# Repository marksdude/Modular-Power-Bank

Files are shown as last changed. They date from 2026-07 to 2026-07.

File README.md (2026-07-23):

# Modular-Power-Bank
A power bank with attachable modules
# Disclamer
None of the PCBs have been fully tested so I can't guarantee that they will function correctly.
# Features
- USB PD output up to 45W (may handle 60W)
- 0.91 inch OLED for status monitoring
- Attachable modules
- Repairable design
# Modules
- LED controller - Allows you to control 5V LEDs with Home Assistant

I also plan to make a LiPo charger module that will support charging up to 3S LiPos.

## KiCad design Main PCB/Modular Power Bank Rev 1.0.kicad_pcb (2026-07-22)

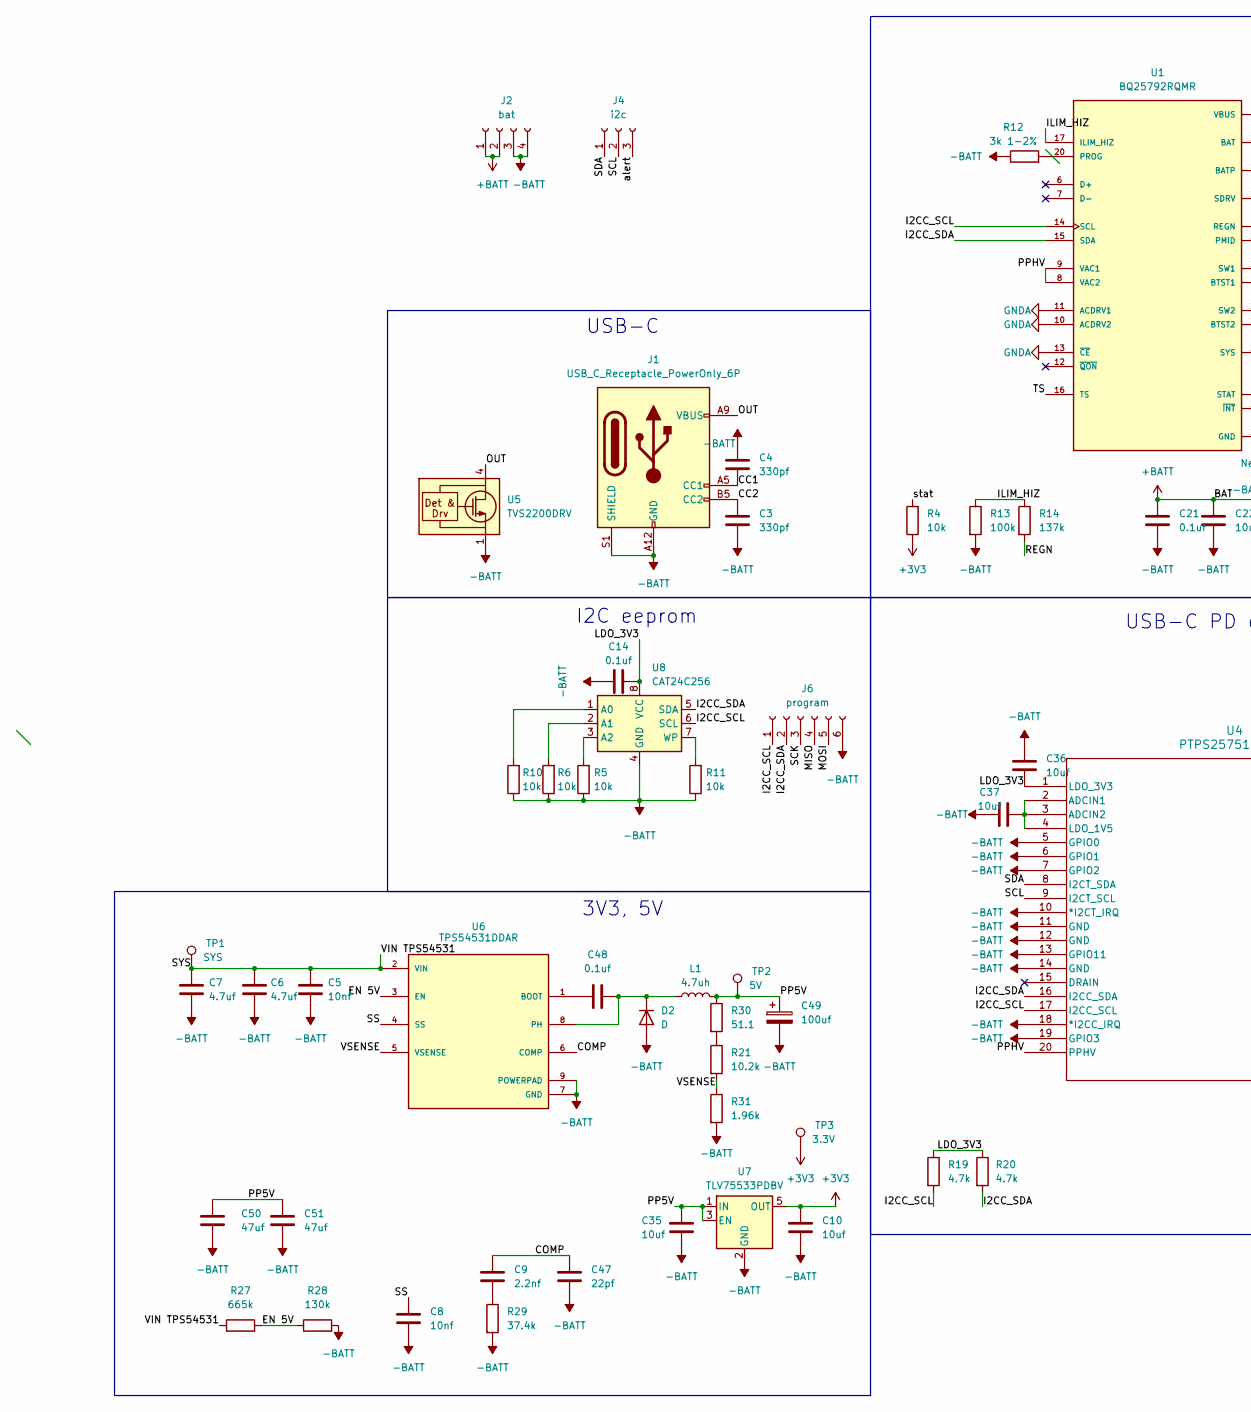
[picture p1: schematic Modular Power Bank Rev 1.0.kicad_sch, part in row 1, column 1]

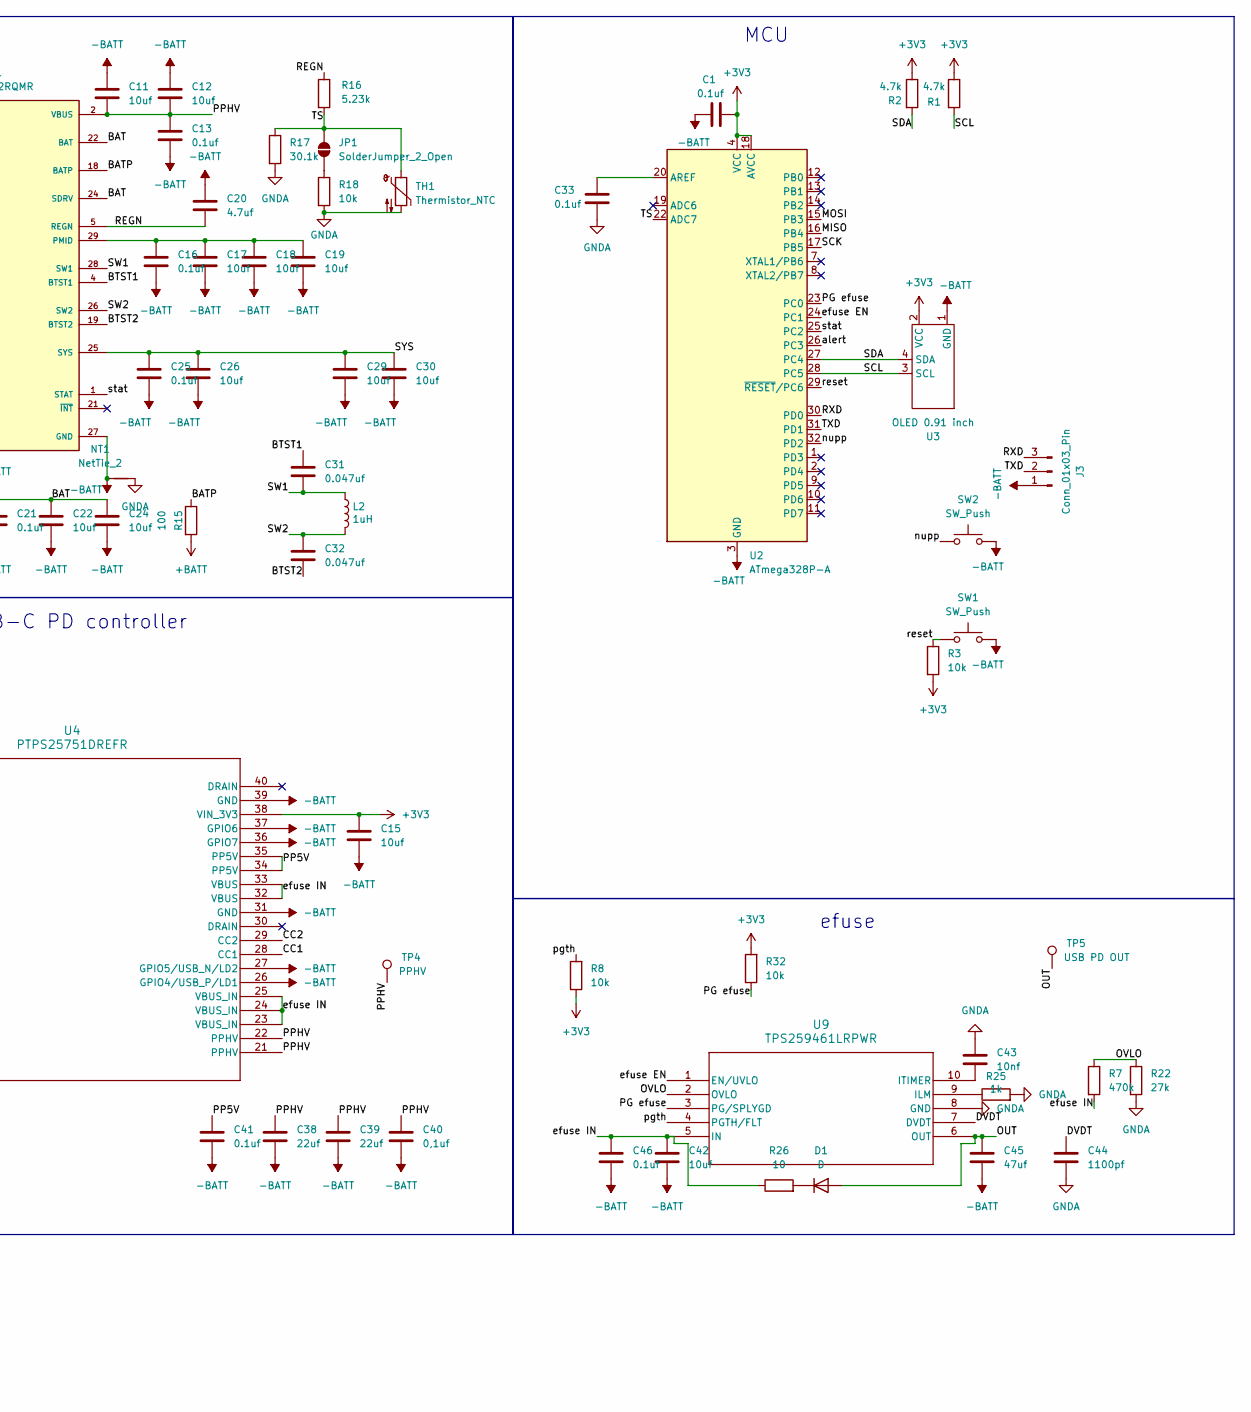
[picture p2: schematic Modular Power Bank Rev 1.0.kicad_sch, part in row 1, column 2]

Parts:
C1, C13, C14, C16, C21, C25, C33, C41, C46, C48: 0.1uf; C_0201_0603Metric_Pad0.64x0.40mm_HandSolder
C3, C4: 330pf; C_0402_1005Metric_Pad0.74x0.62mm_HandSolder
C5, C8, C43: 10nf; C_0201_0603Metric_Pad0.64x0.40mm_HandSolder
C6, C7, C20: 4.7uf; C_0402_1005Metric_Pad0.74x0.62mm_HandSolder
C9: 2.2nf; C_0402_1005Metric_Pad0.74x0.62mm_HandSolder
C10, C11, C12, C22, C24, C26, C29, C30, C35: 10uf; C_0603_1608Metric_Pad1.08x0.95mm_HandSolder
C15, C36, C37: 10uf; C_0402_1005Metric_Pad0.74x0.62mm_HandSolder
C17, C18, C19, C42: 10uf; R_0603_1608Metric_Pad0.98x0.95mm_HandSolder
C31, C32: 0.047uf; C_0402_1005Metric_Pad0.74x0.62mm_HandSolder
C38, C39: 22uf; C_0805_2012Metric_Pad1.18x1.45mm_HandSolder
C40: 0,1uf; C_0201_0603Metric_Pad0.64x0.40mm_HandSolder
C44: 1100pf; C_0402_1005Metric_Pad0.74x0.62mm_HandSolder
C45, C50, C51: 47uf; C_1210_3225Metric_Pad1.33x2.70mm_HandSolder
C47: 22pf; C_0402_1005Metric_Pad0.74x0.62mm_HandSolder
C49: 100uf; CP_Radial_D5.0mm_P2.50mm
D1: D; D_SOD-323_HandSoldering
D2: D; D_SMC
J1: USB_C_Receptacle_PowerOnly_6P; USB_C_Receptacle_GCT_USB4125-xx-x-0190_6P_TopMnt_Horizontal
J2: bat; JST_VH_S4P-VH_1x04_P3.96mm_Horizontal
J3: Conn_01x03_Pin; JST_ZH_B3B-ZR_1x03_P1.50mm_Vertical
J4: i2c; JST_ZH_B3B-ZR_1x03_P1.50mm_Vertical
J6: program; JST_ZH_B6B-ZR_1x06_P1.50mm_Vertical
JP1: SolderJumper_2_Open; SolderJumper-2_P1.3mm_Open_Pad1.0x1.5mm
L1: 4.7uh; L_Bourns_SRP1038C_10.0x10.0mm
L2: 1uH; L_Vishay_IHLP-2020
NT1: NetTie_2; NetTie-2_THT_Pad0.3mm
R1, R2: 4.7k; R_0603_1608Metric_Pad0.98x0.95mm_HandSolder
R3, R18, R32: 10k; R_0603_1608Metric_Pad0.98x0.95mm_HandSolder
R4, R5, R6, R8, R10, R11: 10k; R_0402_1005Metric_Pad0.72x0.64mm_HandSolder
R7: 470k; R_0402_1005Metric_Pad0.72x0.64mm_HandSolder
R12: 3k 1-2%; R_0402_1005Metric_Pad0.72x0.64mm_HandSolder
R13: 100k; R_0603_1608Metric_Pad0.98x0.95mm_HandSolder
R14: 137k; R_0603_1608Metric_Pad0.98x0.95mm_HandSolder
R15: 100; R_0402_1005Metric_Pad0.72x0.64mm_HandSolder
R16: 5.23k; R_0603_1608Metric_Pad0.98x0.95mm_HandSolder
R17: 30.1k; R_0603_1608Metric_Pad0.98x0.95mm_HandSolder
R19, R20: 4.7k; R_0402_1005Metric_Pad0.72x0.64mm_HandSolder
R21: 10.2k; R_0603_1608Metric_Pad0.98x0.95mm_HandSolder
R22: 27k; R_0402_1005Metric_Pad0.72x0.64mm_HandSolder
R25: 1k; R_0402_1005Metric_Pad0.72x0.64mm_HandSolder
R26: 10; R_0402_1005Metric_Pad0.72x0.64mm_HandSolder
R27: 665k; R_0603_1608Metric_Pad0.98x0.95mm_HandSolder
R28: 130k; R_0603_1608Metric_Pad0.98x0.95mm_HandSolder
R29: 37.4k; R_0402_1005Metric_Pad0.72x0.64mm_HandSolder
R30: 51.1; R_0603_1608Metric_Pad0.98x0.95mm_HandSolder
R31: 1.96k; R_0603_1608Metric_Pad0.98x0.95mm_HandSolder
SW1, SW2: SW_Push; SW_SPST_B3U-1000P
TH1: Thermistor_NTC; ntc
TP1: SYS; TestPoint_Pad_D1.0mm
TP2: 5V; TestPoint_Pad_D1.0mm
TP3: 3.3V; TestPoint_Pad_D1.0mm
TP4: PPHV; TestPoint_Pad_D1.0mm
TP5: USB PD OUT; TestPoint_Pad_D1.0mm
U1: BQ25792RQMR; QFN40P400X400X100-29N; PARTREV 11/2019
U2: ATmega328P-A; TQFP-32_7x7mm_P0.8mm
U3: OLED 0.91 inch; SSD1306-0.91-OLED-4pin-128x32
U4: PTPS25751DREFR; WQFN38_REF_TEX
U5: TVS2200DRV; WSON-6-1EP_2x2mm_P0.65mm_EP1x1.6mm
U6: TPS54531DDAR; CONV_TPS54531DDAR; PARTREV A
U7: TLV75533PDBV; SOT-23-5
U8: CAT24C256; SOIC-8_3.9x4.9mm_P1.27mm
U9: TPS259461LRPWR; VQFN10_RPW_TEX

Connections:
+3V3: C1.2, C10.1, C15.1, R1.1, R2.1, R3.2, R4.1, R8.1, R32.2, TP3.1 (1_1), U2.4 (VCC), U2.6 (VCC), U2.18 (AVCC), U3.2 (VCC), U4.38 (VIN_3V3), U7.5 (OUT)
+BATT: C21.1, C22.1, C24.1, J2.1, J2.2, R15.2, U1.22 (BAT), U1.23 (BAT), U1.24 (SDRV)
-BATT: C1.1, C3.2, C4.1, C5.2, C6.2, C7.1, C8.2, C10.2, C11.1, C12.1, C13.1, C14.2, C15.2, C16.2, C17.2, C18.2, C19.2, C20.1, C21.2, C22.2, C24.2, C25.2, C26.2, C29.2, C30.2, C35.2, C36.2, C37.2, C38.2, C39.2, C40.2, C41.2, C42.2, C45.2, C46.2, C47.2, C49.2, C50.2, C51.2, D2.2 (A), J1.A12 (GND), J1.B12 (GND), J1.S1 (SHIELD), J2.3, J2.4, J3.1, J6.6, NT1.1, R5.1, R6.1, R10.1, R11.1, R12.1, R13.2, R28.2, R29.2, R31.2, SW1.2, SW2.2, U1.27 (GND), U2.3 (GND), U2.5 (GND), U2.21 (GND), U3.1 (GND), U4.5 (GPIO0), U4.6 (GPIO1), U4.7 (GPIO2), U4.10 (*I2CT_IRQ), U4.11 (GND), U4.12 (GND), U4.13 (GPIO11), U4.14 (GND), U4.18 (*I2CC_IRQ), U4.19 (GPIO3), U4.26 (GPIO4/USB_P/LD1), U4.27 (GPIO5/USB_N/LD2), U4.31 (GND), U4.36 (GPIO7), U4.37 (GPIO6), U4.39 (GND), U5.1 (GND), U5.2 (GND), U5.3 (GND), U5.7 (GND), U6.7 (GND), U6.9 (POWERPAD), U7.2 (GND), U8.4 (GND)
/BATP: R15.1, U1.18 (BATP)
/BTST1: C31.1, U1.4 (BTST1)
/BTST2: C32.2, U1.19 (BTST2)
/CC1: C4.2, J1.A5 (CC1), U4.28 (CC1)
/CC2: C3.1, J1.B5 (CC2), U4.29 (CC2)
/COMP: C9.1, C47.1, U6.6 (COMP)
/DVDT: C44.1, U9.7 (DVDT)
/EN 5V: R27.2, R28.1, U6.3 (EN)
/I2CC_SCL: J6.1, R19.2, U1.14 (SCL), U4.17 (I2CC_SCL), U8.6 (SCL)
/I2CC_SDA: J6.2, R20.2, U1.15 (SDA), U4.16 (I2CC_SDA), U8.5 (SDA)
/ILIM_HIZ: R13.1, R14.1, U1.17 (ILIM_HIZ)
/LDO_3V3: C14.1, C36.1, R19.1, R20.1, U4.1 (LDO_3V3), U8.8 (VCC)
/MISO: J6.4, U2.16 (PB4)
/MOSI: J6.5, U2.15 (PB3)
/OUT: C45.1, D1.2 (A), J1.A9 (VBUS), J1.B9 (VBUS), TP5.1 (1_1), U5.4 (IN), U5.5 (IN), U5.6 (IN), U9.6 (OUT)
/OVLO: R7.1, R22.1, U9.2 (OVLO)
/PG efuse: R32.1, U2.23 (PC0), U9.3 (PG/SPLYGD)
/PP5V: C35.1, C41.1, C49.1, C50.1, C51.1, L1.2, R30.1, TP2.1 (1_1), U4.34 (PP5V), U4.35 (PP5V), U7.1 (IN), U7.3 (EN)
/REGN: C20.2, R14.2, R16.1, U1.5 (REGN)
/RXD: J3.3, U2.30 (PD0)
/SCK: J6.3, U2.17 (PB5)
/SCL: J4.2, R1.2, U2.28 (PC5), U3.3 (SCL), U4.9 (I2CT_SCL)
/SDA: J4.1, R2.2, U2.27 (PC4), U3.4 (SDA), U4.8 (I2CT_SDA)
/SS: C8.1, U6.4 (SS)
/SW1: C31.2, L2.1, U1.28 (SW1)
/SW2: C32.1, L2.2, U1.26 (SW2)
/SYS: C5.1, C6.1, C7.2, C25.1, C26.1, C29.1, C30.1, R27.1, TP1.1 (1_1), U1.25 (SYS), U6.2 (VIN)
/TS: JP1.1 (A), R16.2, R17.1, TH1.1, U1.16 (TS), U2.22 (ADC7)
/TXD: J3.2, U2.31 (PD1)
/VSENSE: R21.2, R31.1, U6.5 (VSENSE)
/alert: J4.3, U2.26 (PC3)
/efuse EN: U2.24 (PC1), U9.1 (EN/UVLO)
/efuse IN: C42.1, C46.1, R7.2, R26.1, U4.23 (VBUS_IN), U4.24 (VBUS_IN), U4.25 (VBUS_IN), U4.32 (VBUS), U4.33 (VBUS), U9.5 (IN)
/nupp: SW2.1, U2.32 (PD2)
/pgth: R8.2, U9.4 (PGTH/FLT)
/reset: R3.1, SW1.1, U2.29 (~RESET/PC6)
/stat: R4.2, U1.1 (STAT), U2.25 (PC2)
GNDA: C33.2, C43.1, C44.2, NT1.2, R17.2, R18.2, R22.2, R25.2, TH1.2, U1.10 (ACDRV2), U1.11 (ACDRV1), U1.13 (~CE), U9.8 (GND)
unnamed: C9.2, R29.1
unnamed: D1.1 (K), R26.2
unnamed: C48.2, D2.1 (K), L1.1, U6.8 (PH)
unnamed: JP1.2 (B), R18.1
unnamed: R21.1, R30.2
unnamed: C16.1, C17.1, C18.1, C19.1, U1.29 (PMID)
unnamed: R12.2, U1.20 (PROG)
unnamed: C33.1, U2.20 (AREF)
unnamed: C37.1, U4.2 (ADCIN1), U4.3 (ADCIN2), U4.4 (LDO_1V5)
unnamed: C48.1, U6.1 (BOOT)
unnamed: R10.2, U8.1 (A0)
unnamed: R6.2, U8.2 (A1)
unnamed: R5.2, U8.3 (A2)
unnamed: R11.2, U8.7 (WP)
unnamed: R25.1, U9.9 (ILM)
unnamed: C43.2, U9.10 (ITIMER)
VBUS: C11.2, C12.2, C13.2, C38.1, C39.1, C40.1, TP4.1 (1_1), U1.2 (VBUS), U1.3 (VBUS), U1.8 (VAC2), U1.9 (VAC1), U4.20 (PPHV), U4.21 (PPHV), U4.22 (PPHV)

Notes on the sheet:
USB-C PD controller
MCU
3V3, 5V
I2C eeprom
efuse
USB-C

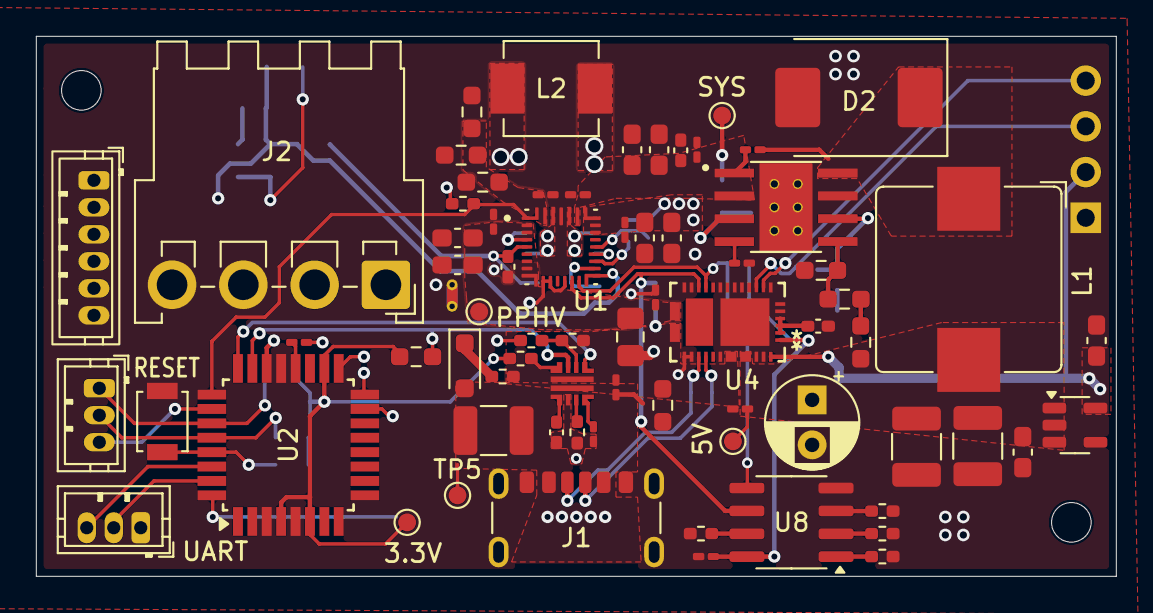
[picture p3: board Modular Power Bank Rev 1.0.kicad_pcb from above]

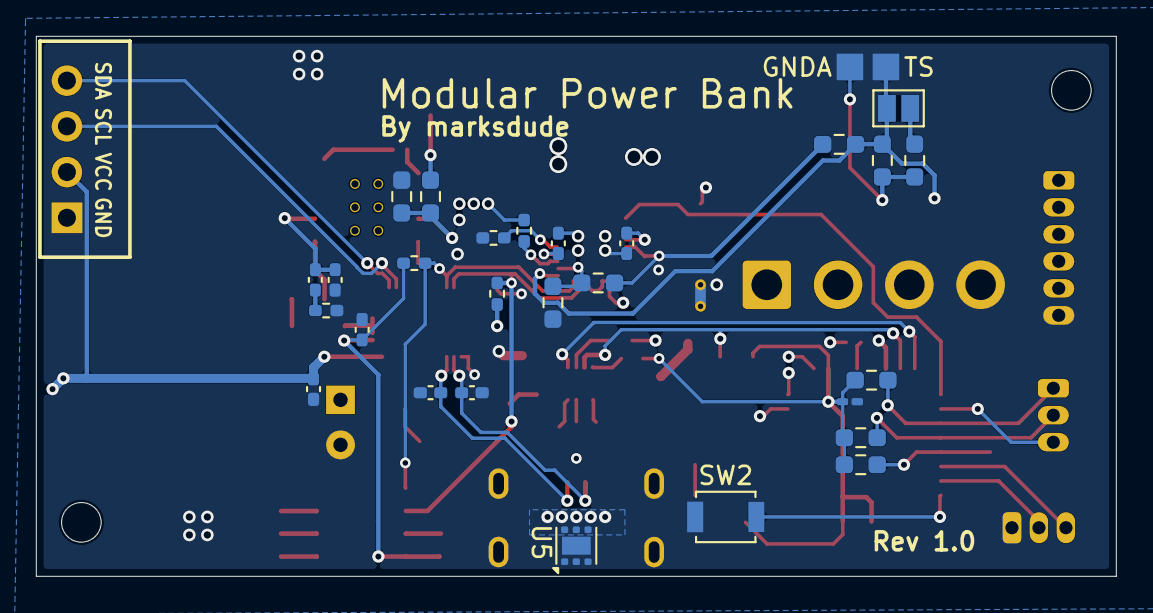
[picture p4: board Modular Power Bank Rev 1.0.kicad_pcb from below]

Board: 4 copper layers, 60.0 x 30.0 mm, 100 parts (29 on the bottom side), 58 nets.

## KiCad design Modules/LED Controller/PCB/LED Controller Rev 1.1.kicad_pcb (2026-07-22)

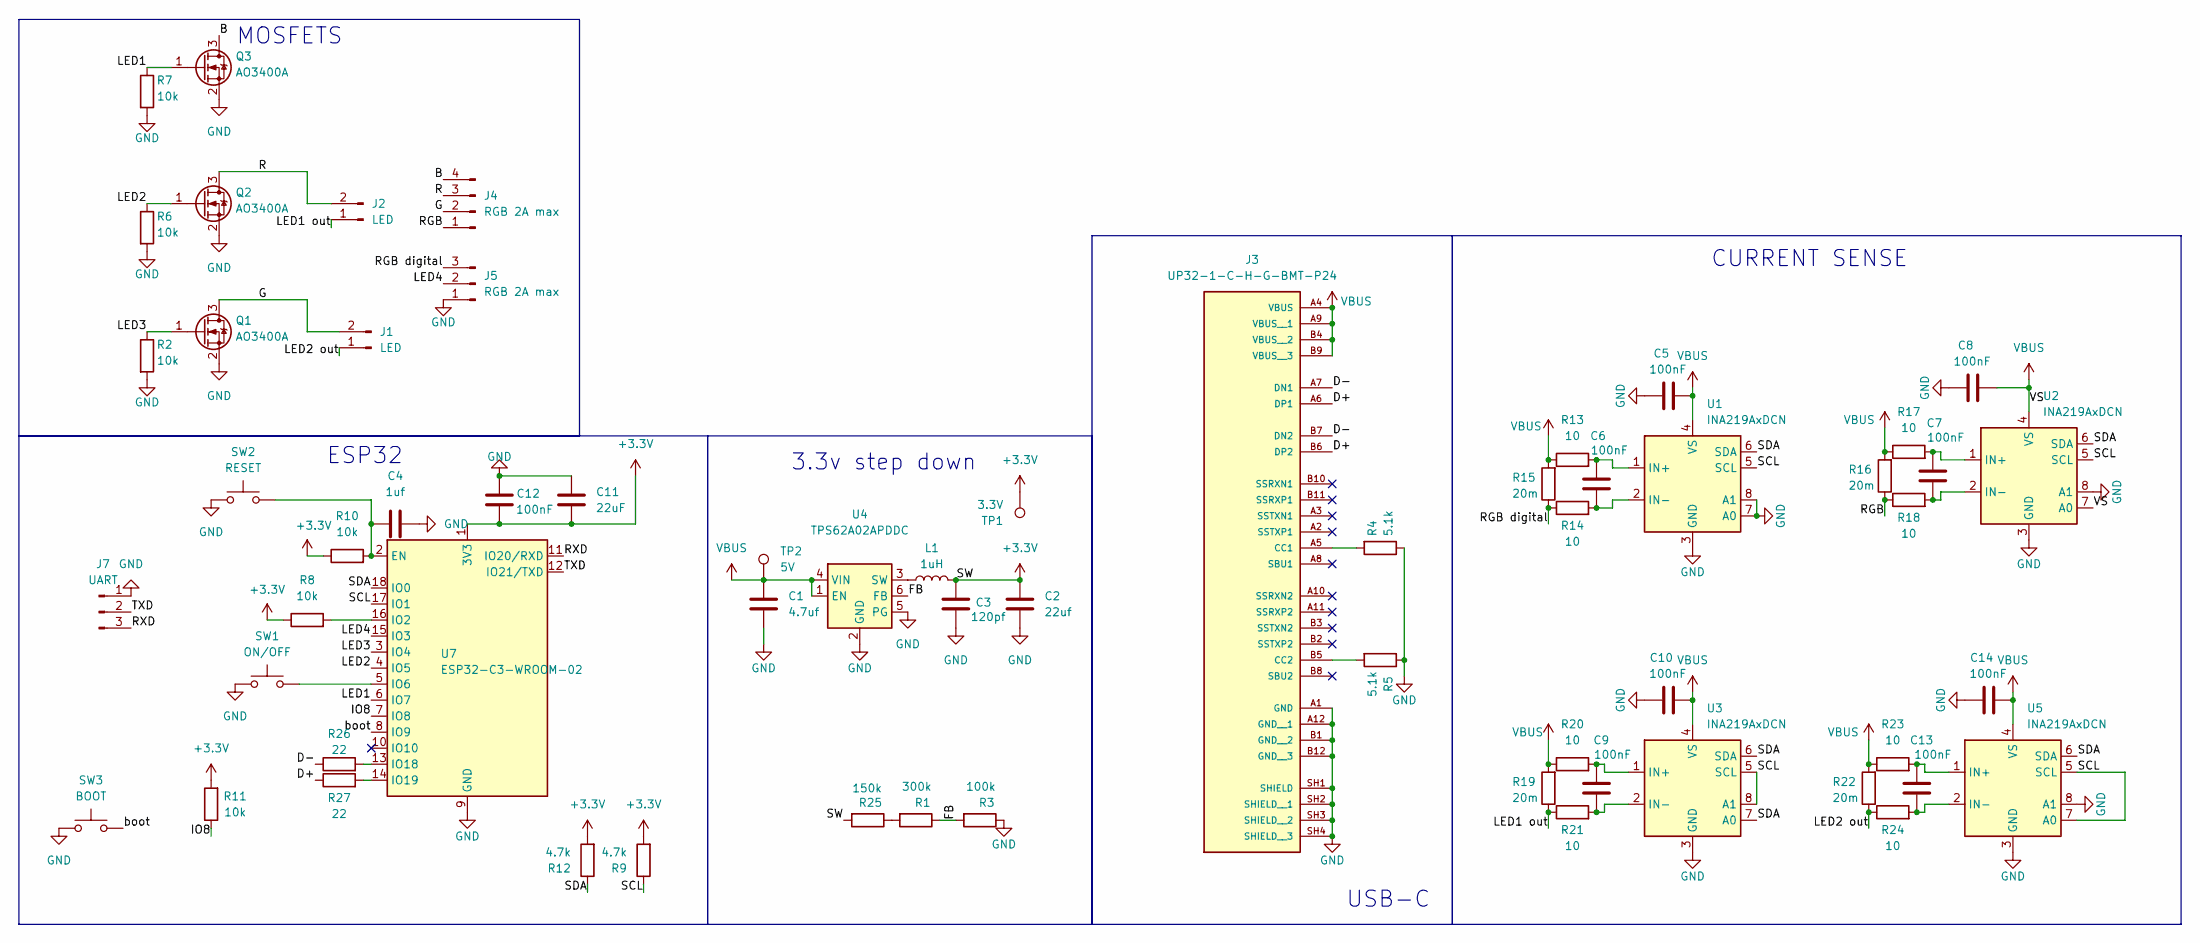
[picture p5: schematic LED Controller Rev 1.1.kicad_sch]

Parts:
C1: 4.7uf; C_0603_1608Metric_Pad1.08x0.95mm_HandSolder
C2: 22uf; C_0603_1608Metric_Pad1.08x0.95mm_HandSolder
C3: 120pf; C_0402_1005Metric_Pad0.74x0.62mm_HandSolder
C4: 1uf; C_0603_1608Metric_Pad1.08x0.95mm_HandSolder
C5, C6, C7, C9, C10, C12, C13, C14: 100nF; C_0402_1005Metric_Pad0.74x0.62mm_HandSolder
C8: 100nF; C_0201_0603Metric_Pad0.64x0.40mm_HandSolder
C11: 22uF; C_0603_1608Metric_Pad1.08x0.95mm_HandSolder
J1, J2: LED; JST_XH_S2B-XH-A-1_1x02_P2.50mm_Horizontal
J3: UP32-1-C-H-G-BMT-P24; SAMESKY_UP32-1-C-H-G-BMT-P24; PARTREV 1.0
J4: RGB 2A max; JST_XH_S4B-XH-A-1_1x04_P2.50mm_Horizontal
J5: RGB 2A max; JST_XH_S3B-XH-A-1_1x03_P2.50mm_Horizontal
J7: UART; JST_ZH_B3B-ZR_1x03_P1.50mm_Vertical
L1: 1uH; L_1008_2520Metric_Pad1.43x2.20mm_HandSolder
Q1, Q2, Q3: AO3400A; SOT-23
R1: 300k; R_0402_1005Metric_Pad0.72x0.64mm_HandSolder
R2, R6, R7, R8, R10, R11: 10k; R_0603_1608Metric_Pad0.98x0.95mm_HandSolder
R3: 100k; R_0603_1608Metric_Pad0.98x0.95mm_HandSolder
R4, R5: 5.1k; R_0603_1608Metric_Pad0.98x0.95mm_HandSolder
R9, R12: 4.7k; R_0603_1608Metric_Pad0.98x0.95mm_HandSolder
R13, R14, R17, R18, R20, R21, R23, R24: 10; R_0402_1005Metric_Pad0.72x0.64mm_HandSolder
R15, R16, R19, R22: 20m; R_0805_2012Metric_Pad1.20x1.40mm_HandSolder
R25: 150k; R_0402_1005Metric_Pad0.72x0.64mm_HandSolder
R26, R27: 22; R_0402_1005Metric_Pad0.72x0.64mm_HandSolder
SW1: ON/OFF; SW_SPST_B3U-1000P
SW2: RESET; SW_SPST_B3U-1000P
SW3: BOOT; SW_SPST_B3U-1000P
TP1: 3.3V; TestPoint_Pad_D1.0mm
TP2: 5V; TestPoint_Pad_D1.0mm
U1, U2, U3, U5: INA219AxDCN; SOT-23-8
U4: TPS62A02APDDC; SOT-23-6
U7: ESP32-C3-WROOM-02; ESP32-C3-WROOM-02U

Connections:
+3.3V: C2.1, C3.1, C11.2, C12.2, L1.2, R8.1, R9.2, R10.1, R11.2, R12.2, R25.2, TP1.1 (1_1), U7.1 (3V3)
/B: J4.4, Q3.3 (D)
/D+: J3.A6 (DP1), J3.B6 (DP2), R27.1
/D-: J3.A7 (DN1), J3.B7 (DN2), R26.1
/FB: R1.1, R3.2, U4.6 (FB)
/G: J1.2, J4.2, Q1.3 (D)
/IO8: R11.1, U7.7 (IO8)
/LED1: Q3.1 (G), R7.1, U7.6 (IO7)
/LED1 out: J2.1, R19.1, R21.1
/LED2: Q2.1 (G), R6.1, U7.4 (IO5)
/LED2 out: J1.1, R22.1, R24.1
/LED3: Q1.1 (G), R2.1, U7.3 (IO4)
/LED4: J5.2, U7.15 (IO3)
/R: J2.2, J4.3, Q2.3 (D)
/RGB: J4.1, R16.1, R18.1
/RGB digital: J5.3, R14.1, R15.1
/RXD: J7.3, U7.11 (IO20/RXD)
/SCL: R9.1, U1.5 (SCL), U2.5 (SCL), U3.5 (SCL), U3.8 (A1), U5.5 (SCL), U5.7 (A0), U7.17 (IO1)
/SDA: R12.1, U1.6 (SDA), U2.6 (SDA), U3.6 (SDA), U3.7 (A0), U5.6 (SDA), U7.18 (IO0)
/TXD: J7.2, U7.12 (IO21/TXD)
/boot: SW3.2, U7.8 (IO9)
GND: C1.2, C2.2, C3.2, C4.1, C5.1, C8.1, C10.1, C11.1, C12.1, C14.1, J3.A1 (GND), J3.A12 (GND__1), J3.B1 (GND__2), J3.B12 (GND__3), J3.SH1 (SHIELD), J3.SH2 (SHIELD__1), J3.SH3 (SHIELD__2), J3.SH4 (SHIELD__3), J5.1, J7.1, Q1.2 (S), Q2.2 (S), Q3.2 (S), R2.2, R3.1, R4.1, R5.1, R6.2, R7.2, SW1.1, SW2.1, SW3.1, U1.3 (GND), U1.7 (A0), U1.8 (A1), U2.3 (GND), U2.8 (A1), U3.3 (GND), U4.2 (GND), U4.5 (PG), U5.3 (GND), U5.8 (A1), U7.9 (GND), U7.19 (GND)
unnamed: J3.A5 (CC1), R4.2
unnamed: J3.B5 (CC2), R5.2
unnamed: R1.2, R25.1
unnamed: C6.1, R13.2, U1.1 (IN+)
unnamed: C6.2, R14.2, U1.2 (IN-)
unnamed: C7.1, R17.2, U2.1 (IN+)
unnamed: C7.2, R18.2, U2.2 (IN-)
unnamed: C9.1, R20.2, U3.1 (IN+)
unnamed: C9.2, R21.2, U3.2 (IN-)
unnamed: L1.1, U4.3 (SW)
unnamed: C13.1, R23.2, U5.1 (IN+)
unnamed: C13.2, R24.2, U5.2 (IN-)
unnamed: C4.2, R10.2, SW2.2, U7.2 (EN)
unnamed: R8.2, U7.16 (IO2)
unnamed: SW1.2, U7.5 (IO6)
unnamed: R26.2, U7.13 (IO18)
unnamed: R27.2, U7.14 (IO19)
VBUS: C1.1, C5.2, C8.2, C10.2, C14.2, J3.A4 (VBUS), J3.A9 (VBUS__1), J3.B4 (VBUS__2), J3.B9 (VBUS__3), R13.1, R15.2, R16.2, R17.1, R19.2, R20.1, R22.2, R23.1, TP2.1 (1_1), U1.4 (VS), U2.4 (VS), U2.7 (A0), U3.4 (VS), U4.1 (EN), U4.4 (VIN), U5.4 (VS)

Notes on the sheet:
ESP32
USB-C
CURRENT SENSE
3.3v step down
MOSFETS

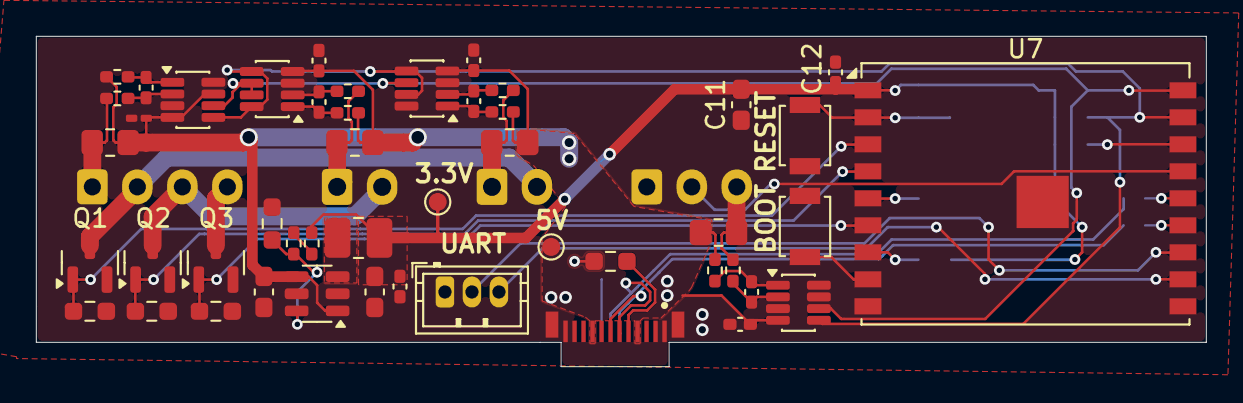
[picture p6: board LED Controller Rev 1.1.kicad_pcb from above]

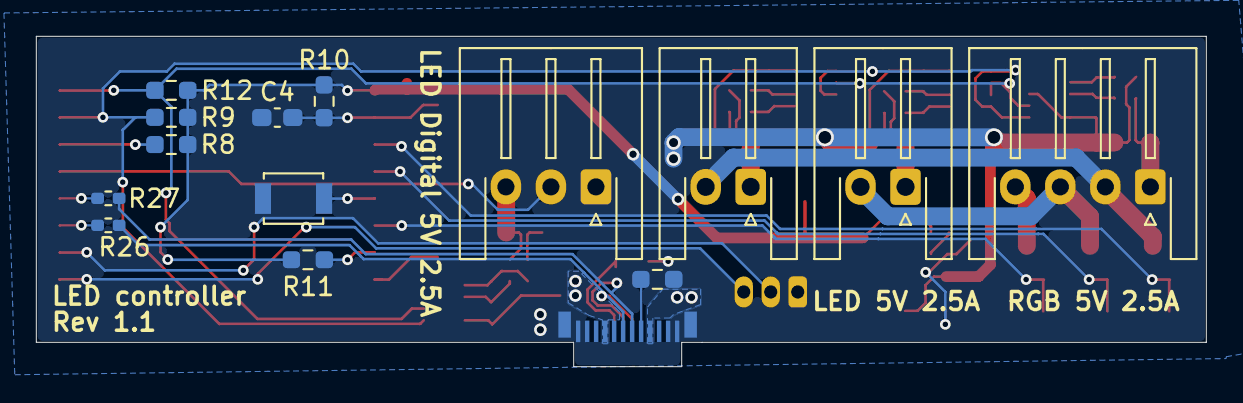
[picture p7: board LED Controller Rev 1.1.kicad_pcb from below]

Board: 2 copper layers, 65.0 x 18.4 mm, 62 parts (14 on the bottom side), 40 nets.

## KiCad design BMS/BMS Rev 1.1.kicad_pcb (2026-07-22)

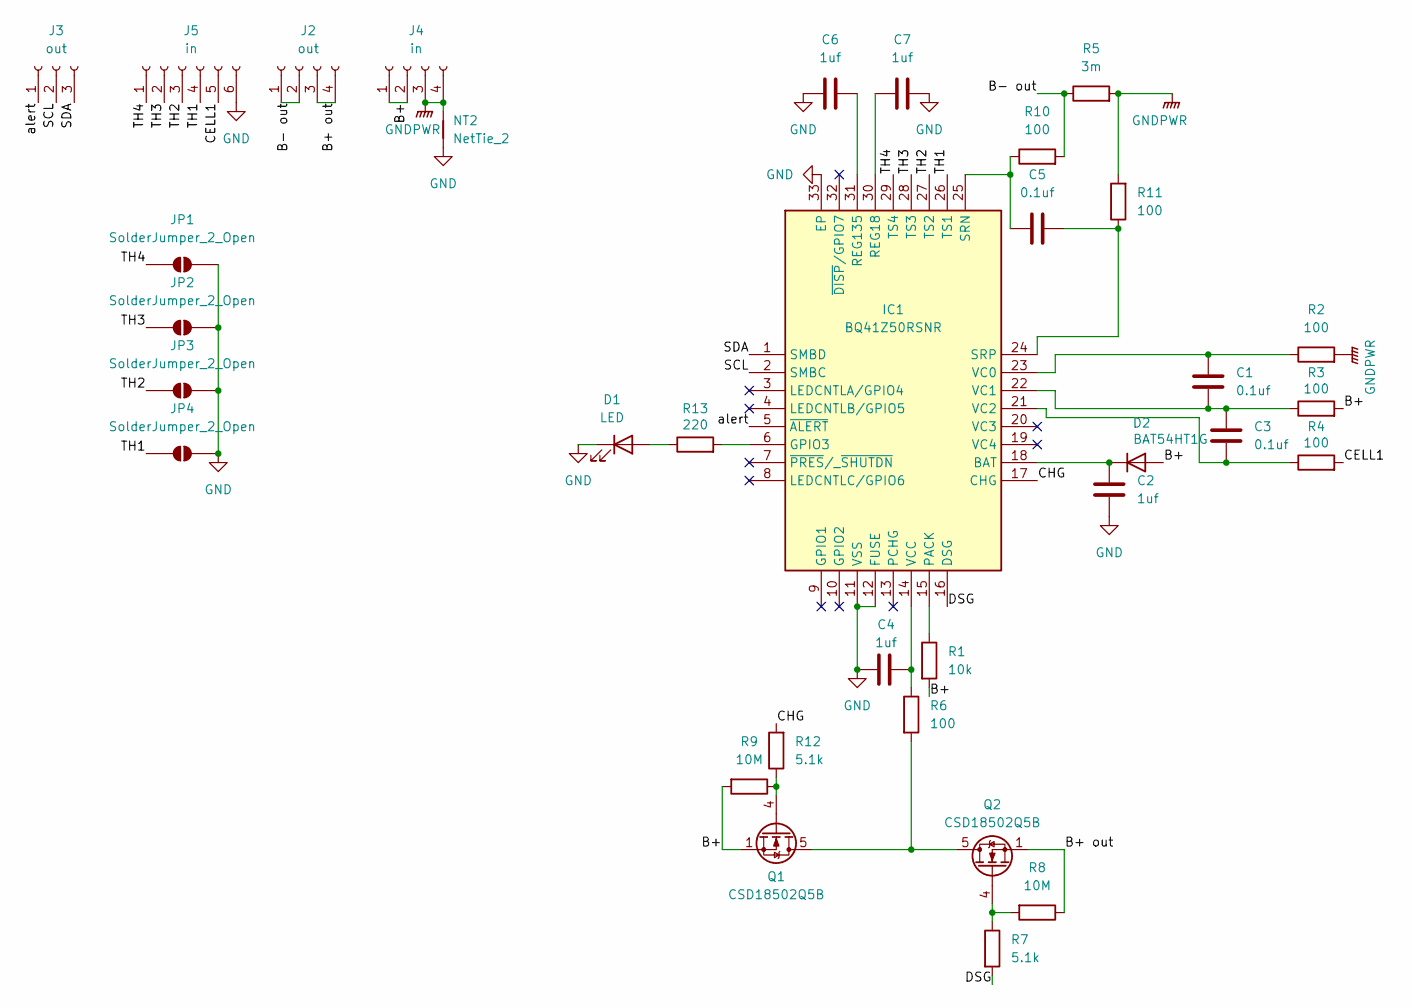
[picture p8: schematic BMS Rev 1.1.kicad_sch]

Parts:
C1, C3: 0.1uf; C_0402_1005Metric_Pad0.74x0.62mm_HandSolder
C2, C4, C6, C7: 1uf; C_0402_1005Metric_Pad0.74x0.62mm_HandSolder
C5: 0.1uf; C_0201_0603Metric_Pad0.64x0.40mm_HandSolder
D1: LED; LED_0402_1005Metric_Pad0.77x0.64mm_HandSolder
D2: BAT54HT1G; D_SOD-323_HandSoldering
IC1: BQ41Z50RSNR; QFN40P400X400X80-33N-D; Manufacturer_Part_Number BQ41Z50RSNR
J2: out; JST_VH_S4P-VH_1x04_P3.96mm_Horizontal
J3: out; JST_ZH_B3B-ZR_1x03_P1.50mm_Vertical
J4: in; JST_VH_S4P-VH_1x04_P3.96mm_Horizontal
J5: in; JST_ZH_B6B-ZR_1x06_P1.50mm_Vertical
JP1, JP2, JP3, JP4: SolderJumper_2_Open; SolderJumper-2_P1.3mm_Open_RoundedPad1.0x1.5mm
NT2: NetTie_2; NetTie-2_SMD_Pad0.5mm
Q1, Q2: CSD18502Q5B; TDSON-8-1
R1: 10k; R_0603_1608Metric_Pad0.98x0.95mm_HandSolder
R2, R3, R4, R10, R11: 100; R_0402_1005Metric_Pad0.72x0.64mm_HandSolder
R5: 3m; R_2512_6332Metric_Pad1.40x3.35mm_HandSolder
R6: 100; R_0603_1608Metric_Pad0.98x0.95mm_HandSolder
R7, R12: 5.1k; R_0402_1005Metric_Pad0.72x0.64mm_HandSolder
R8, R9: 10M; R_0402_1005Metric_Pad0.72x0.64mm_HandSolder
R13: 220; R_0402_1005Metric_Pad0.72x0.64mm_HandSolder

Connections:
/B+: D2.2 (A), J4.1, J4.2, Q1.1 (S), Q1.2 (S), Q1.3 (S), R1.2, R3.2, R9.2
/B+ out: J2.3, J2.4, Q2.1 (S), Q2.2 (S), Q2.3 (S), R8.1
/B- out: J2.1, J2.2, R5.1, R10.2
/CELL1: J5.5, R4.2
/CHG: IC1.17 (CHG), R12.2; also elsewhere on the board
/DSG: IC1.16 (DSG), R7.2; also elsewhere on the board
/SCL: IC1.2 (SMBC), J3.2; also elsewhere on the board
/SDA: IC1.1 (SMBD), J3.3; also elsewhere on the board
/TH1: IC1.26 (TS1), J5.4, JP4.1 (A); also elsewhere on the board
/TH2: IC1.27 (TS2), J5.3, JP3.1 (A); also elsewhere on the board
/TH3: IC1.28 (TS3), J5.2, JP2.1 (A); also elsewhere on the board
/TH4: IC1.29 (TS4), J5.1, JP1.1 (A); also elsewhere on the board
/alert: IC1.5 (~ALERT), J3.1; also elsewhere on the board
GND: C2.2, C4.1, C6.1, C7.2, D1.1 (K), IC1.11 (VSS), IC1.12 (FUSE), IC1.33 (EP), J5.6, JP1.2 (B), JP2.2 (B), JP3.2 (B), JP4.2 (B), NT2.1; also elsewhere on the board
GNDPWR: J4.3, J4.4, NT2.2, R2.2, R5.2, R11.2
unnamed: D1.2 (A), R13.1
unnamed 16: C2.1, D2.1 (K), IC1.18 (BAT); also elsewhere on the board
unnamed 17: IC1.6 (GPIO3), R13.2; also elsewhere on the board
unnamed 18: IC1.15 (PACK), R1.1; also elsewhere on the board
unnamed 19: C7.1, IC1.30 (REG18); also elsewhere on the board
unnamed 20: C6.2, IC1.31 (REG135); also elsewhere on the board
unnamed 21: C5.1, IC1.25 (SRN), R10.1; also elsewhere on the board
unnamed 22: C5.2, IC1.24 (SRP), R11.1; also elsewhere on the board
unnamed 23: C1.1, IC1.23 (VC0), R2.1; also elsewhere on the board
unnamed 24: C1.2, C3.1, IC1.22 (VC1), R3.1; also elsewhere on the board
unnamed 25: C3.2, IC1.21 (VC2), R4.1; also elsewhere on the board
unnamed 26: C4.2, IC1.14 (VCC), R6.1; also elsewhere on the board
unnamed: Q1.5 (D), Q2.5 (D), R6.2
unnamed: Q1.4 (G), R9.1, R12.1
unnamed: Q2.4 (G), R7.1, R8.2

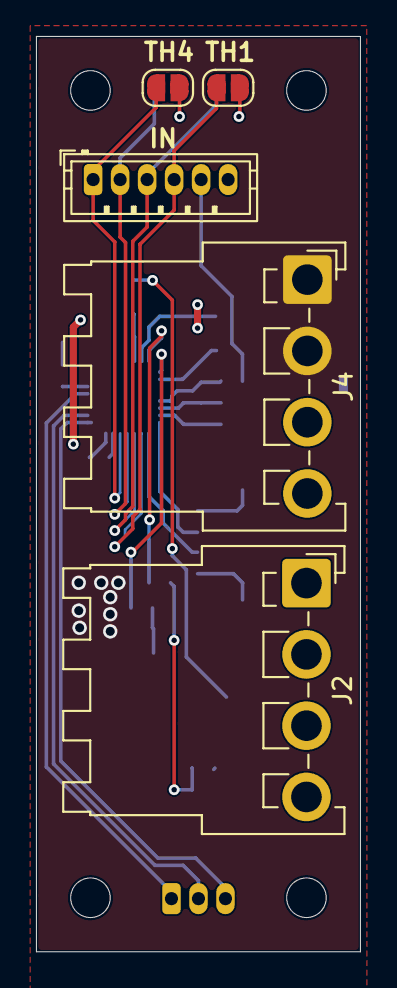
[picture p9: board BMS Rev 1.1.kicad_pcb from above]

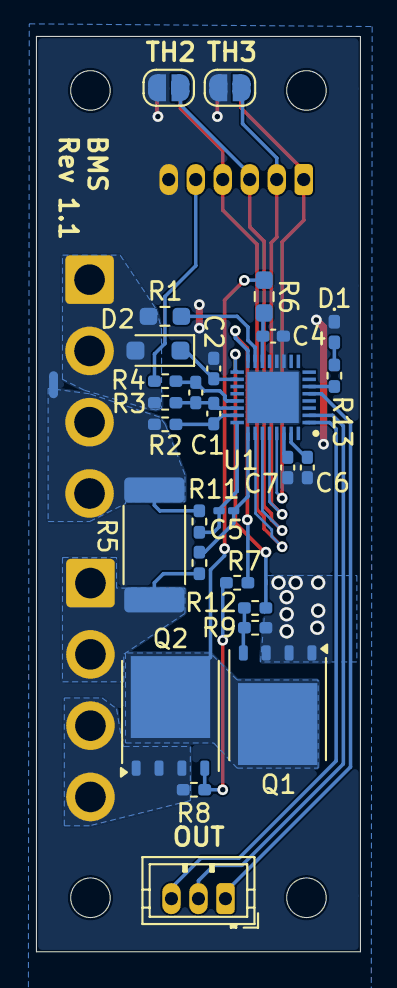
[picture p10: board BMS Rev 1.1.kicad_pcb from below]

Board: 2 copper layers, 18.0 x 50.8 mm, 34 parts (29 on the bottom side), 30 nets.

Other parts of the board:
U1: BQ41Z50RSNR; QFN40P400X400X80-33N-D

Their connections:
/CHG: U1.17 (CHG); also elsewhere on the board
/DSG: U1.16 (DSG); also elsewhere on the board
/SCL: U1.2 (SMBC); also elsewhere on the board
/SDA: U1.1 (SMBD); also elsewhere on the board
/TH1: U1.26 (TS1); also elsewhere on the board
/TH2: U1.27 (TS2); also elsewhere on the board
/TH3: U1.28 (TS3); also elsewhere on the board
/TH4: U1.29 (TS4); also elsewhere on the board
/alert: U1.5 (~ALERT); also elsewhere on the board
GND: U1.11 (VSS), U1.12 (FUSE), U1.33 (EP); also elsewhere on the board
unnamed 16: U1.18 (BAT); also elsewhere on the board
unnamed 17: U1.6 (GPIO3); also elsewhere on the board
unnamed 18: U1.15 (PACK); also elsewhere on the board
unnamed 19: U1.30 (REG18); also elsewhere on the board
unnamed 20: U1.31 (REG135); also elsewhere on the board
unnamed 21: U1.25 (SRN); also elsewhere on the board
unnamed 22: U1.24 (SRP); also elsewhere on the board
unnamed 23: U1.23 (VC0); also elsewhere on the board
unnamed 24: U1.22 (VC1); also elsewhere on the board
unnamed 25: U1.21 (VC2); also elsewhere on the board
unnamed 26: U1.14 (VCC); also elsewhere on the board
